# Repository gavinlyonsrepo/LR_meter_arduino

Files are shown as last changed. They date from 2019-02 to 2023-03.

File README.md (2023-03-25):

    

Table of contents
---------------------------

  * [Overview](#overview)
  * [Software used](#software-used)
  * [Libraries](#libraries)
  * [Parts list](#parts-list)
  * [Push button control](#push-button-control)
  * [Features](#features)

Overview
--------------------
* Name : LR_meter_arduino
* Title : Inductance and Resistance meter, Arduino based.
* Description : 
	* Inductance and Resistance meter.
	* Arduino based. 
	* 4 resistor test ranges,  Resistor range is from 0 ohms to 2 Mohms. Auto-range.
	* Inductance test, range is 80uH to 30,000uH.
	* ADC measurement display test.
    * Push button input.
    * Outputs data to serial monitor and OLED.

* Author: Gavin Lyons

Software used
------------------
Arduino 1.8.5 & Eagle 9.0.1

Libraries
------------------------
* <Adafruit_SSD1306.h> // OLED 1.1.2

Parts List
------------------------------
The schematic and Parts list are available in documentation folder.

Push button control
-------------------------------

Push Buttons
1. Mode Button to change mode
2. Test button to start test for selected mode.

Tests Modes:

1. Inductance test.
2. 0 to 2k range resistor test.
3. 2K to 20k range resistor test.
4. 20k to 200k range resistor test.
5. 200k to 1M range resistor test.
6. Display ADC in digital value and Voltage.

Features
-----------------------------------------------

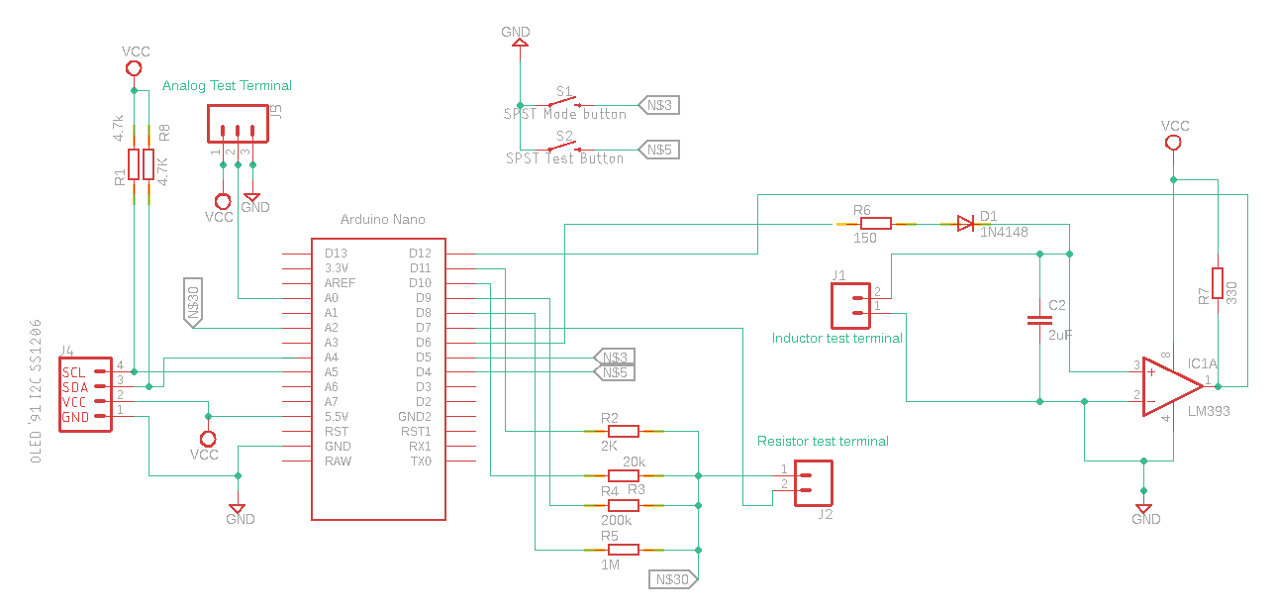
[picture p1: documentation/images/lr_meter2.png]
ScreenShot schematic


**Resistance test**

The resistors used in circuit should be measured on good quality meter 
and there exact values added to code for maximum accuracy. As of Version 2.2 This Resistance test can now auto-range in both directions. 

0-2kohms : 2kohms resistor

2k-20k : 20k resistor

20k-200k : 200k resistor

200k - 1Mohm : 1 Mohm resistor

So we will use a basic voltage divider to calculate the resistance. 

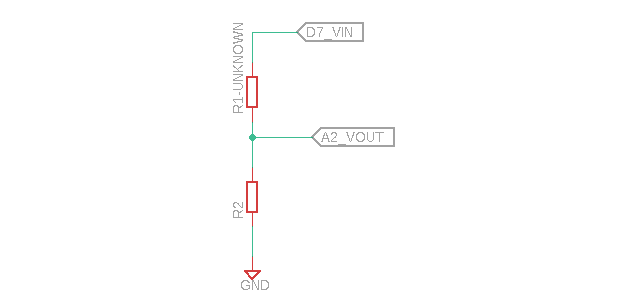
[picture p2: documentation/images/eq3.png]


A voltage divider is made of two Resistances (R1 and R2) in series. The output voltage in the middle point is [R2/(R1+R2)]Vin. Using this formula and knowing the value of R2 and measuring the Vout calculate the resistance of R1. 
Vin will be 5 volts from the Arduino, We can measure Vout with one of the Arduino's analog inputs.
We need to use different ranges of R2 to measure with better precision. 

**Inductance test**

This tests range is from 80uH to 30,000uH. Ideally the capacitors in circuit must be in specification and measured on a good quality meter. The unknown test inductor is placed in parallel with a capacitor thus creating an LC circuit. 

As soon as the voltage on the LC circuit becomes positive, the LM393 will be floating, which can be pulled high with a pull up resistor. When the voltage on the LC circuit becomes negative, the LM393 will pull its output to ground. 

A 5V pulse signal from Arduino is applied to the LC circuit. We charge the circuit for some time. Then we change the voltage from 5 volts directly to 0. That pulse will make the circuit resonate creating a  sinusoidal signal oscillating at the resonant frequency. The frequency is measured and later using the formulas we can obtain the inductance value. We will use the Arduino to measure the frequency and calculate the value. The resonant frequency is measured with the next equation: 

ScreenShot seq 1

So we could obtain the L value because we know the F frequency that we've just measured and we also know the value of the capacitor because it's a component that we've selected. All we need is to obtain L from this equation.

ScreenShot seq 2

The comparator will turn the sine wave into a square wave with a duty of 50%(see fig 9 in 
[datasheet](https://www.onsemi.com/pub/Collateral/LM393-D.PDF)),  The microcontroller measures the signal , This measurement can then be doubled to get the period and the inverse of the period is the frequency. Since the circuit is resonating, this frequency is the resonating frequency.

We can now solve the equation for inductance.

**Display ADC in digital value and Voltage.**

This displays the voltage and ADC digital value measured on A0, This can be used for testing potentiometers,
sensors or measuring voltage levels.

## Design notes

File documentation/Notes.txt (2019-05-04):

ZIF TEST socket pin layout
----------------------------------

1. A2 n/c n/c n/c R    R  R R 

2. A0 n/c GND n/c VCC n/c L L 

Resistors values used in code:

1. 2.005 Kohms
2. 20.03 Kohms
3. 218   Kohms
4. 1.006 Mohms 

Capacitor value

1. 2uF

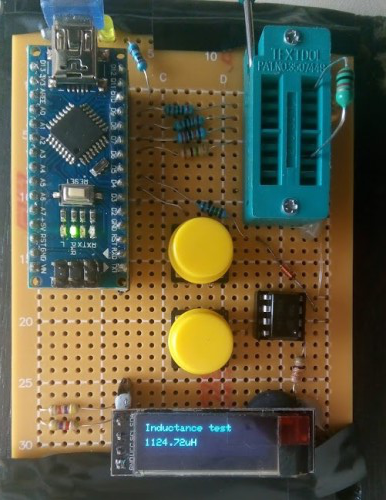
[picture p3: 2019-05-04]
documentation/images/project.jpg

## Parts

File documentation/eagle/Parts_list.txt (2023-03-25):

Parts List:

>
> I2C 0.91" inch 128x32 OLED Display Module Driver IC: SSD1306.
>
> Arduino NANO or UNO
>
> Resistors: 2kohms, 20kohms, 200kohms, 1Mohms, 150ohm, 330ohm, 4.7Kohms X 2 .
>
> Capacitors: 2 uF non-polarized  
>
> Two push buttons.
>
> Diode:  1N4001 or IN4148
>
> LM393 comparator IC [datasheet](https://www.onsemi.com/pub/Collateral/LM393-D.PDF) or LM339
>
> ZIF test socket , Output terminal or socket connections
>

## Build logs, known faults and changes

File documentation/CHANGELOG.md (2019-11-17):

### Changelog

* version 1.0-1 June 2018 
	* first release

* Version 2.0-1 Feb 2019
	* Added OLED for output in addition to serial output.
	* Replaced joysticks control with pushbuttons.
	* Analog input display added.
	* Status LED added.

* Version 2.1-2 April 2019
	* Added pull up resistors for OLED I2C.
	* Added initialize value of zero to variables in Inductance function,
	  in order to prevent random values being reported in event of zero pulse.
	* Finalized resistor values for finished produced prototype PCB.

* Version 2.2-3 November 2019
	* Adding upscale Auto-ranging to resistor test.
	* Added help message.

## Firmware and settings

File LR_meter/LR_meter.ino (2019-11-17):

/*
  Name : LR_meter_ardunio
  Title : Resistance and Inductance meter. Ardunio ucontroller based.
  Description : Inductance and Resistance meter, Arduino based. 3 tests,
  4 resistor test ranges. One Inductance test, push button input ,
  outputs to serial monitor and OLED 1602. Resistor range is from 0 ohms to 2 Mohms ,
  Inductor range is 80uH to 30,000uH. Also includes Analog ADc display
  Author: Gavin Lyons
  URL: https://github.com/gavinlyonsrepo/LR_meter_arduino
*/

//****************** Libraries ********************
#include <Adafruit_SSD1306.h> // OLED 1.1.2

//***************** GLOBALS ********************

// Push Button pin
#define buttonTest 4
#define buttonMode 5

// Variables to debounce switches
int buttonTestState;             // the current reading from the input pin
int lastButtonTestState = HIGH;   // the previous reading from the input pin
// the following variable are unsigned longs because the time, measured in
// milliseconds, will quickly become a bigger number than can be stored in an int.
unsigned long lastDebounceTestTime = 0;  // the last time the output pin was toggled

int buttonModeState;             // the current reading from the input pin
int lastButtonModeState = HIGH;   // the previous reading from the input pin
// the following variable are unsigned longs because the time, measured in
// milliseconds, will quickly become a bigger number than can be stored in an int.
unsigned long lastDebounceModeTime = 0;  // the last time the output pin was toggled
unsigned long debounceDelay = 50;    // the debounce time; 

// Var to hold menu mode
uint8_t mode = 0;

//ADC display.
const int analogPinADC = 0; //analog pin read for ADC display

// resistor test pin numbers
const int analogPin = 2; //analog pin read for resistor test
const int apply_voltage = 7;  //digital pin to resitor unknown apply 5V
// Known Resistors connected to these 4 digital pins
const int Res2K = 11;
const int Res20K = 10;
const int Res200K = 9;
const int Res1M = 8;

// Inductance test pin numbers
const int OutLtestPin = 6; //digital pin input to circuit to "ring" LC circuit
const int PulseInPin = 12; //digital pin to read in pulse

// OLED data
#define OLED_RESET 4
Adafruit_SSD1306 display(OLED_RESET);

//**************** FUNCTION PROTOTYPES ***********
void DisplayInit();
void Serialinit();
void GPIOinit();
void OLEDready();
void DisplayHelpMsg();
void ResScaleOne();
void ResScaleTwo();
void ResScaleThree();
void ResScaleFour();
void Ltest();
void AnalogDisplay();
float calcResult(float R1, int multi_factor);
void PrintResult(String unit, float R2);
void printMenuMsg();
void TestRun();
void ReadPushButtonMode();
void ReadPushButtonTest();

//*************** SETUP *************
void setup()
{
  Serialinit();
  GPIOinit();
  DisplayInit();
}

//******************* MAIN LOOP *****************
void loop()
{
  ReadPushButtonMode();
  ReadPushButtonTest();
  delay(50);
}

// ********************* Functions *************************

// Function to display help message related to PCB socket layout
void DisplayHelpMsg()
{
  display.clearDisplay();
  display.setCursor(0, 0);
  display.setTextSize(1);
  display.setTextColor(WHITE);
  display.print("Connector pinout");
  display.setCursor(0, 12);
  display.print("Row1 : R1  RRRR");
  display.setCursor(0, 22);
  display.print("Row2 : A G V LL");
  display.display();
  delay(5000);
  OLEDready();
}

//Function to init OLED and display OLED  welcome message
void DisplayInit()
{
  display.begin(SSD1306_SWITCHCAPVCC, 0x3C);
  display.clearDisplay();
  display.setCursor(0, 0);
  display.setTextSize(2);
  display.setTextColor(WHITE);
  display.print("LR Meter");
  display.setCursor(0, 15);
  display.print("G. Lyons");
  display.display();
  delay(1000);
  OLEDready();
}

//Function to display Ready message on OLED and serial monitor
void OLEDready()
{
  display.clearDisplay();
  display.display();
  display.setCursor(0, 0);
  display.setTextSize(2);
  display.setTextColor(WHITE);
  display.print("      MODE");
  display.setCursor(0, 15);
  display.print("Ready TEST");
  display.display();
  Serial.println("LR Meter Ready");
  digitalWrite(LED_BUILTIN, HIGH);
  mode = 0;
  delay(50);
}

//Function to setup serial called from setup
void Serialinit()
{
  Serial.begin(9600);
  delay(100);
  Serial.println("-------------LR Meter Comms UP------------");
}

//Function to init GPIO pins on ATmega328p setup called from setup
void GPIOinit()
{
   // Status LED
   pinMode(LED_BUILTIN, OUTPUT);
   digitalWrite(LED_BUILTIN, HIGH);  
   delay(100);                    
   digitalWrite(LED_BUILTIN, LOW);
  
  // Setup pins for button enable internal pull-up resistors
  digitalWrite(buttonMode, HIGH);
  digitalWrite(buttonTest, HIGH);

  // Set resistor measurement pins
  pinMode(analogPin, INPUT);
  pinMode(apply_voltage, OUTPUT);
  // Set known resistor pins as inputs
  pinMode(Res2K, INPUT);
  pinMode(Res20K, INPUT);
  pinMode(Res200K, INPUT);
  pinMode(Res1M, INPUT);

  //Inductance test pins
  pinMode(PulseInPin, INPUT);
  pinMode(OutLtestPin, OUTPUT);
}

//Function ResScaleOne :resistor 0 to 2k range test.
void ResScaleOne()
{
  digitalWrite(apply_voltage, HIGH);
  pinMode(Res2K, OUTPUT);
  pinMode(Res20K, INPUT);
  pinMode(Res200K, INPUT);
  pinMode(Res1M, INPUT);
  digitalWrite(Res2K, LOW);
  float R2 = 0;
  float R1 = 2.005; // Set this value to the value of the used resistor in K ohms
  R2 = calcResult(R1, 1000);
  if (R2 > (R1 * 1000))
  {
    Serial.println("Increasing Scale");
    mode = 2; //increase scale
    printMenuMsg();
    //ResetResRange();
    ResScaleTwo();
  }
  if (R2 < (R1 * 1000))
  {
    PrintResult("ohms", R2);
  }
}

//Function ResScaleTwo: resistor 2K to 20k range test.
void ResScaleTwo()
{
  digitalWrite(apply_voltage, HIGH);
  pinMode(Res2K, INPUT);
  pinMode(Res20K, OUTPUT);
  pinMode(Res200K, INPUT);
  pinMode(Res1M, INPUT);
  digitalWrite(Res20K, LOW);
  float R2 = 0;
  float R1 = 18.3; // Set this value to the value of the used resistor in K ohms
  R2 = calcResult(20.03, 1);
  if (R2 > R1)
  {
    Serial.println("Increasing Scale");
    mode = 3; //increase scale
    printMenuMsg();
    //ResetResRange();
    ResScaleThree();
  }
  if (R2 < R1)
  {
    PrintResult("k ohms", R2);
  }
}

//Function ResScaleThree : resistor test 20k to 200k range test.
void ResScaleThree()
{
  digitalWrite(apply_voltage, HIGH);
  pinMode(Res2K, INPUT);
  pinMode(Res20K, INPUT);
  pinMode(Res200K, OUTPUT);
  pinMode(Res1M, INPUT);
  digitalWrite(Res200K, LOW);
  float R2 = 0;
  float R1 = 218; // Set this value to the value of the used resistor in K ohms
  R2 = calcResult(R1, 1);
  if (R2 > R1)
  {
    Serial.println("Increasing Scale");
    mode = 4; //increase scale
    printMenuMsg();
    //ResetResRange();
    ResScaleFour();
  }
  if (R2 < R1)
  {
    PrintResult("k ohms",  R2);
  }
}
//Function ResScaleFour : resistence test 200k to 1M range test.
void ResScaleFour()
{
  digitalWrite(apply_voltage, HIGH);
  pinMode(Res2K, INPUT);
  pinMode(Res20K, INPUT);
  pinMode(Res200K, INPUT);
  pinMode(Res1M, OUTPUT);
  digitalWrite(Res1M, LOW);
  float R2 = 0;
  float R1 = 1006;// Set first value to the value of the used resistor in Kohms
  R2 = calcResult(R1, 1);
  if (R2 > 2000)
  {
    mode = 8; //Beyond Scale Too high
    printMenuMsg();
  }
  if (R2 < 2000)
  {
    if (R2 <= 10)
    {
       Serial.println("Decreasing Scale");
       mode = 1; //decrease scale
       printMenuMsg();
       //ResetResRange();
       ResScaleOne(); 
       return;  
    }
    PrintResult("M ohms", (R2/1000));
  }
}

// Function: calcResult to calculate unknown resistor value
// Inputs: (2) 1, float R1 known resistor value for given scale
// 2, Integer multiple factor either 1 or 1000 depending on given scale.
// Outputs: returns 1, float R2 unknown resitor value
float calcResult(float R1, int multi_factor)
{
  float R2 = 0;
  float tmpbuffer = 0;
  int V_measured = 0;
  uint8_t Vin = 5;
  float Vout = 0;
  const uint8_t numReadings = 11; // number of analog samples
  int readings[numReadings];      // the readings from the analog input

  // Get 11(numreadings) values from ADC 
  for (int thisReading = 0; thisReading < numReadings; thisReading++)
  {
    readings[thisReading] = analogRead(analogPin); // ADC
    if (thisReading != 0) // ignore first reading as it is bad during auto-range.
    {
      V_measured  = V_measured + readings[thisReading]; //running total
    }
  }
  V_measured = (V_measured /(numReadings-1)); // average
  
  Vout = (V_measured * Vin) / 1024.0; //Convert ADC to voltage
  tmpbuffer = (Vin / Vout) - 1; //voltage divider (VIN/VOUT -1)
  R2 = R1 * tmpbuffer * multi_factor;  // R2 = R1(Vin/Vout -1) 
  return R2;
}

// Function to print various messages input based on Menu push button press
void printMenuMsg()
{
  display.clearDisplay();
  display.setCursor(0, 0);
  display.setTextSize(1);
  display.setTextColor(WHITE);
  switch (mode)
  {
    case (0):
      __asm__("nop\n\t");
      break;
    case (1):
      display.print("R 0k - 2k range");
      display.display();
      Serial.println("0k to 2k range");
      break;
    case (2):
      display.print("R 2k - 20k range");
      display.display();
      Serial.println("2k to 20k range");
      break;
    case (3):
      display.print("R 20k - 200k range");
      display.display();
      Serial.println("20k to 200k range");
      break;
    case (4):
      display.print("R  0.2M - 1M range");
      display.display();
      Serial.println("200k to 1M range");
      break;
    case (5):
      display.print("Inductance test");
      display.display();
      Serial.println("Inductance test");
      break;
    case (6):
      display.print("Analog TEST");
      display.display();
      Serial.println("Analog display test");
      break;
    case(7):
         OLEDready();
    break;
    case (8):
      display.print("Out of Scale");
      display.display();
      Serial.println("Out of scale");
      delay(1500);
      OLEDready();
      break;
  }
}

//Function to run tests when test button pressed
void TestRun()
{
    digitalWrite(LED_BUILTIN, LOW);
    switch (mode)
    {  
    case (0):
        DisplayHelpMsg();
        __asm__("nop\n\t");
      break;
    case (1):
        ResScaleOne();
      break;
    case (2):
        ResScaleTwo();
      break;
    case (3):
        ResScaleThree();
      break;
    case (4):
        ResScaleFour();
      break;
    case (5):
        Ltest();
      break;
    case (6):
       AnalogDisplay();
      break;
    }
  digitalWrite(LED_BUILTIN, HIGH);
}

//Function PrintResult : Print calculated resistor value and unit to serial monitor
//Inputs (2) : 1 , String unit unit of resistance Kohms Mohms ,
// 2, float R2 , value of resistance calculated
void PrintResult(String unit, float R2)
{
  Serial.println("Resistance: ");
  Serial.print(R2);
  Serial.print(" ");
  Serial.println(unit);

  display.setCursor(0, 15);
  display.print(R2);
  display.print(unit);
  display.display();
  delay(2000);

  OLEDready();
}

//Function to display ADC and voltage value at analog input
void AnalogDisplay()
{
  float ADCValue = 0;
  float VoltValue = 0;
  while(1)
  {
  float ADCValue = analogRead(analogPinADC);
  VoltValue = (ADCValue*0.0048828125);  // ADC*(5/1024)
  Serial.print("ADC: ");
  Serial.println(ADCValue);
  Serial.print("Volt : ");
  Serial.println(VoltValue);

  display.clearDisplay();
  display.setCursor(0, 0);
  display.print("ADC : ");
  display.print( ADCValue);
  display.setCursor(0, 15);
  display.print("Volt : ");
  display.print(VoltValue);
  
  display.display();
  delay(2000);
  }
}
//Function Ltest: Calculates Inductance
void Ltest()
{
  double pulse, frequency, capacitance, inductance = 0;
  digitalWrite(OutLtestPin, HIGH);
  delay(5);//give some time to charge inductor.
  digitalWrite(OutLtestPin, LOW);
  delayMicroseconds(100); //make sure resonation is measured
  pulse = pulseIn(PulseInPin, HIGH, 5000); //returns 0 if timeout
  if (pulse > 0.1) { //pulse returns 0 if no complete pulse was received within the timeout
     
    capacitance = 2.E-6; // - insert Cap value here

    frequency = 1.E6 / (2 * pulse);
    inductance = 1. / (capacitance * frequency * frequency * 4.*3.14159 * 3.14159);
    inductance *= 1E6;
  }

  //Serial print
  Serial.print("High for uS:");
  Serial.println( pulse );
  Serial.print("\tfrequency Hz:");
  Serial.println( frequency );
  Serial.print("\tinductance uH:");
  Serial.println( inductance );

  display.setCursor(0, 12);
  display.print(inductance);
  display.print("uH ");
  display.setCursor(0, 22);
  display.print(frequency);
  display.print("Hz ");
  display.print(pulse);
  display.print("uS ");
  display.display();
  delay(2000);
  OLEDready();
}

// Function to handle debounce of mode menu button
// If debounced and succesful read alter mode var and menu display
void ReadPushButtonMode()
{
   // read and debounce push button.
  int reading = digitalRead(buttonMode);
  // If the switch changed?
  if (reading != lastButtonModeState) {
    // reset the debouncing timer
    lastDebounceModeTime = millis();
  }
  if ((millis() - lastDebounceModeTime) > debounceDelay) {
    // if the button state has changed:
    if (reading != buttonModeState) {
      buttonModeState = reading;
      if (buttonModeState == LOW) {
        mode++;
        printMenuMsg();
      }
    }
  }

  // save the reading.
  lastButtonModeState = reading;
}

// Function to handle debounce of start test button
// If debounced and succesful read start the test.
void ReadPushButtonTest()
{
   // read and debounce push button.
  int reading = digitalRead(buttonTest);
  // If the switch changed?
  if (reading != lastButtonTestState) {
    // reset the debouncing timer
    lastDebounceTestTime = millis();
  }
  if ((millis() - lastDebounceTestTime) > debounceDelay) {
    // if the button state has changed:
    if (reading != buttonTestState) {
      buttonTestState = reading;
      // start test if the new button state is low
      if (buttonTestState == LOW) {
        TestRun();
      }
    }
  }

  // save the reading.
  lastButtonTestState = reading;
}

//******************* EOF *****************

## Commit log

2018-06-06 Version 1.0-1
    [LR_Meter.fzz, LR_meter.brd, LR_meter.sch]
2018-06-08 fixing schematic image view
2019-01-30 updating documentation
    [LR_Meter.fzz]
2019-01-31 Updating design :
    [LR_meter.sch]
2019-02-10 Version 1.1-2
    [LR_meter.sch]
2019-02-20 version 1.1-2, adding OLED
    [LR_meter.sch]
2019-02-26 version 2.0
    [LR_meter.sch]
2019-05-04 version 2.1-2
    [LR_meter.sch]
